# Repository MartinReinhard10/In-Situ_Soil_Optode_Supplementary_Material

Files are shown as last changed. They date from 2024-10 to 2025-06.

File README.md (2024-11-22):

This repository is to function as supplementary material for the paper "A novel, standalone and low-cost system for in-situ chemical imaging with planar optodes in soils": https://doi.org/10.1016/j.snb.2024.136894

Please find 3D files for printing structural components, wiring diagram and information on electronic + additional components required.

For Python scripts regarding operating the imaging system please refer to the repository: https://github.com/MartinReinhard10/Operate_In-Situ_Soil_Optode

# All requests or questions regarding the repository should be directed at: martinreinhard@bio.au.dk
---

# System Hardware
This is a list of electronic, mechanical, and other components used in the OptodeSystem, including a Raspberry Pi 4, HQ Camera, UV-LED, stepper motors, and various sensors. The document also includes a wiring diagram and links to additional resources for each component.

File (.step) with full 3D model of the system can be provided if needed.
---

# Electronic Components

- **Raspberry Pi 4 Model B 4 GB RAM**
    
    [Raspberry Pi Documentation - Computers](https://www.raspberrypi.com/documentation/computers/)
        
    [Armor Aluminium Heatsink Case for Raspberry Pi 4 • RaspberryPi.dk](https://raspberrypi.dk/en/product/armor-aluminium-heatsink-case-for-raspberry-pi-4/)
    
- **Raspberry Pi HQ Camera**
    
    [Raspberry Pi Documentation - Camera](https://www.raspberrypi.com/documentation/accessories/camera.html)
    
- ****16mm Telephoto Lens for Raspberry Pi HQ Camera (C-mount)****
    
    [16mm Telephoto Lens for Raspberry Pi HQ Camera (C-mount) • Mouser.com]([https://raspberrypi.dk/en/product/16mm-telephoto-lens-raspberry-pi-hq-camera/](https://www.mouser.com/pdfDocs/DFRobot16mm10MPTelephotoLensPO.pdf))
    
- **UV-LED  -** 395 nm
    
    [Datasheet UV-LED](https://www.mouser.dk/datasheet/2/245/Luminus_SST_10_UV_Datasheet-1499199.pdf)
      
- **Resistor** - HS25 18R
    
    [acl_hs10-1890310.pdf](https://www.mouser.dk/datasheet/2/303/acl_hs10-1890310.pdf)
    
- **Stepper Motor (x2) -** 17HS08-1004
    
    [Documentation - 17HS08-1004S.pdf](https://www.oyostepper.com/images/upload/File/17HS08-1004S.pdf)
    
- **Stepper Driver** - A4988
    
    [a4988_DMOS_microstepping_driver_with_translator.pdf](https://www.pololu.com/file/0J450/a4988_DMOS_microstepping_driver_with_translator.pdf)
    
    [In-Depth: Control Stepper Motor with A4988 Driver Module & Arduino](https://lastminuteengineers.com/a4988-stepper-motor-driver-arduino-tutorial/)
    
    - **A4988 Expansion Board**
        (https://store.siqma.com/stepper-motor-driver-board.html?search=expansion)
      
        [Raspberry Pi Stepper Motor Control with NEMA 17 — Maker Portal](https://makersportal.com/blog/raspberry-pi-stepper-motor-control-with-nema-17)

- **Temperature & Humidity Sensor** - DHT22
    
    [DHT22 - Datasheet.pdf](https://www.sparkfun.com/datasheets/Sensors/Temperature/DHT22.pdf)
    
- **Distance Sensor (Time-Of-Flight)** - VL53L0X
    
    [m5-docs](https://docs.m5stack.com/en/unit/tof)
    
    [Datasheet - VL53L0X_en.pdf](https://m5stack.oss-cn-shenzhen.aliyuncs.com/resource/docs/datasheet/hat/VL53L0X_en.pdf)
    
- **Limit switch (x2)**
    
    [Mechanical Endstop - RepRap](https://reprap.org/wiki/Mechanical_Endstop)
    
- **5V Relay module**
    
    [5V Single Channel Relay Module](https://microcontrollerslab.com/5v-single-channel-relay-module-pinout-working-interfacing-applications-datasheet/)
    
- **Buck Converter** - LM2596
    
    [LM2596 Buck Converter Datasheet, Pinout, Features, Applications - The Engineering Projects](https://www.theengineeringprojects.com/2020/09/lm2596-buck-converter-datasheet-pinout-features-applications.html)
    
- **12V Cooling Fan (60x60x10mm)**
  
- **Slip Ring**
    
    [SNF-3P%20updated.pdf](https://cdn.sparkfun.com/datasheets/Robotics/SNF-3P%20updated.pdf)
    
- **Power supply - 12V DC 5A**

---

# Mechanical Components

20 x 40mm V-slot Aluminum Extrusion

20mm V-Gantry Plate with Wheels
       
GT2 Belt - 2mm pitch - 6mm width

GT2 Pulley 20 (diameter: 5mm)

Belt Tensioner 2020 Profile X-Axis

Ball Bearings 8x22x7mm (x4)

---

# Other Components

Ø250mm Plexiglass Cylinder  

- Emission Filter
    
    Zircon UV Blue Blocker from Lee Filters is used to cover the camera lens.
    (https://leefilters.com/colour/821-zircon-uv-blue-blocker/)    

Wiring - See Wiring Diagram

Dupont Wire Pin Header Connectors

Cable Ties

Bolts and Nuts for Assembly - See list of nuts & bolts

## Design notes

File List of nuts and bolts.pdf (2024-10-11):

Type | M2.5 | M3 | M4 | M5 | M6
Washer | 4 | 8 | 20 | 23
Washer Large Diameter | | | | | 1
Hex Head Machine Screw 10mm 12mm 14mm 15mm 16mm 20mm 30mm 50mm 5mm 8mm | | 14 8 2 4 | 33 8 15 2 1 4 3 | 23 13 2 2 2 1 3 | 1 1
Hex Nut | 4 | 9 | 6 | 20 | 1
Internal Lockwasher | | 8 | 4 | 12
Flathead Machine screw 10mm 12mm 16mm 4mm | | 12 4 | 2 4 | 1
Philips Machine Screw 10mm 12 mm | 4 | 2
Hex Locknut | | | 1
Hex Acorn Cap Nut | | | | 2
T-Nut 2020 | | | 14

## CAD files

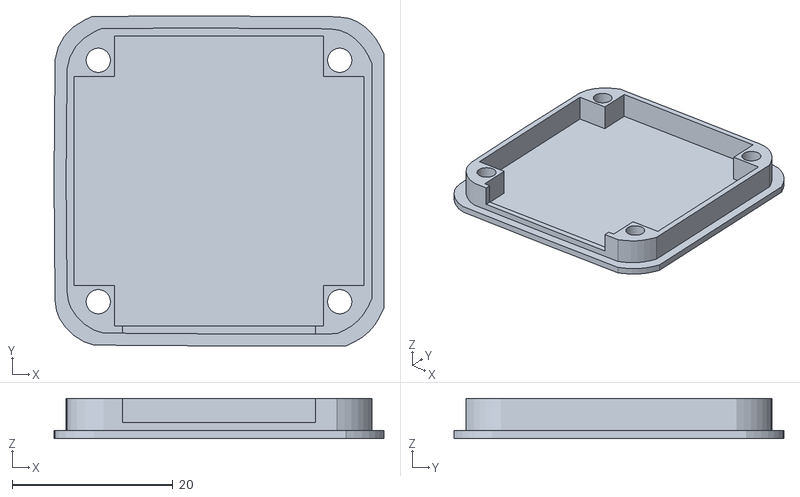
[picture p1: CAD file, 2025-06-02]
3D printing (.stl)/Pi_HQ_Cam_Back_Cover.stl
41.0 x 41.0 x 5.00

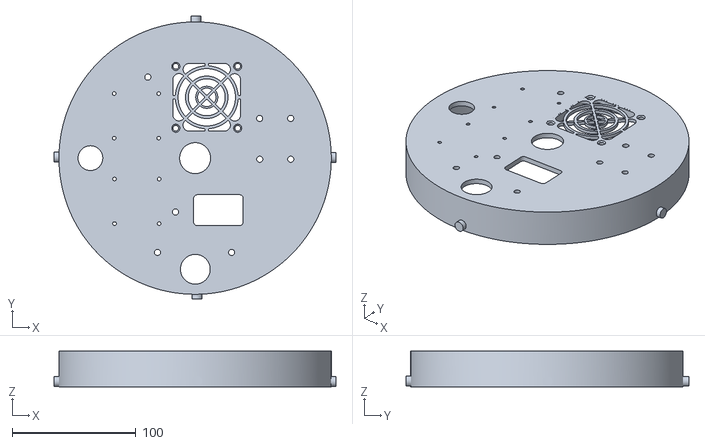
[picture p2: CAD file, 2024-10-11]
3D printing (.stl)/Baseplate.stl
227.6 x 228.6 x 29.0

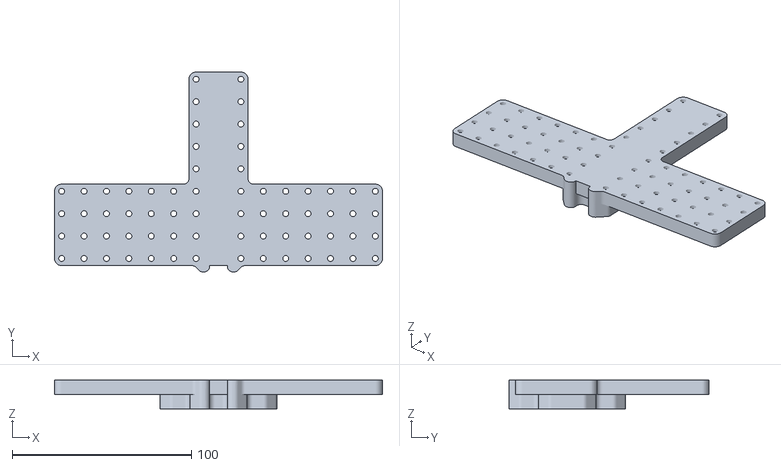
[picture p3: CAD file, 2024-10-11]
3D printing (.stl)/Backframe_mount.stl
183.0 x 111.5 x 16.0

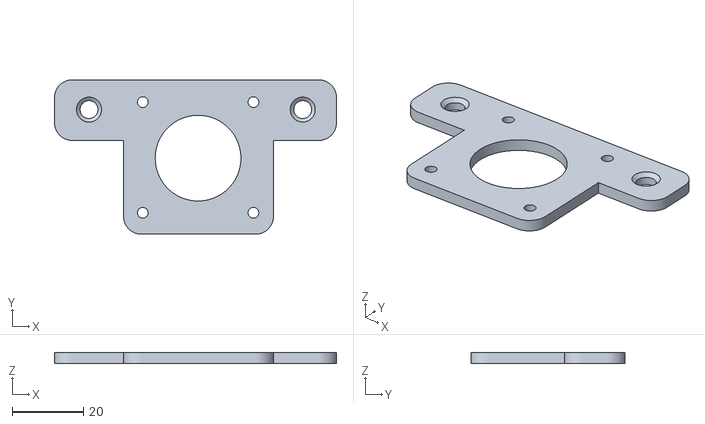
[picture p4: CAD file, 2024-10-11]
3D printing (.stl)/Motor_rotation_bracket.stl
79.0 x 43.2 x 3.00

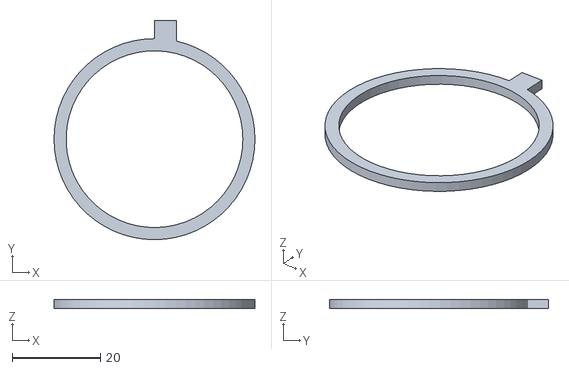
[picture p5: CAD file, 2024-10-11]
3D printing (.stl)/Filter_Lockring.stl
45.5 x 49.6 x 2.00

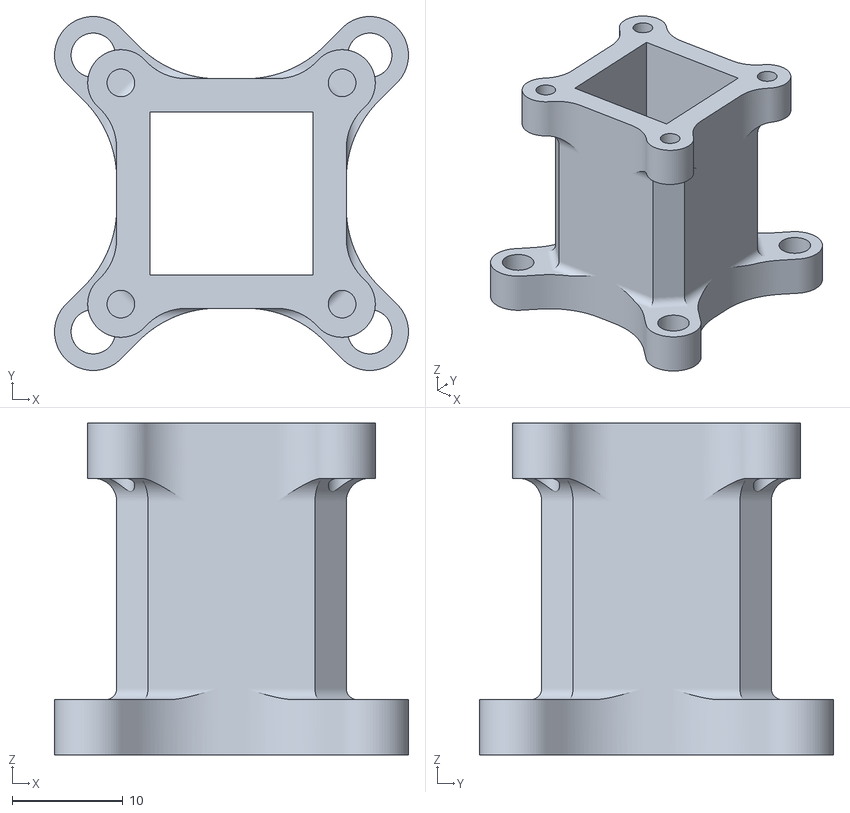
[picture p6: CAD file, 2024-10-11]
3D printing (.stl)/LED_standoff_30mm.stl
32.0 x 32.0 x 30.0

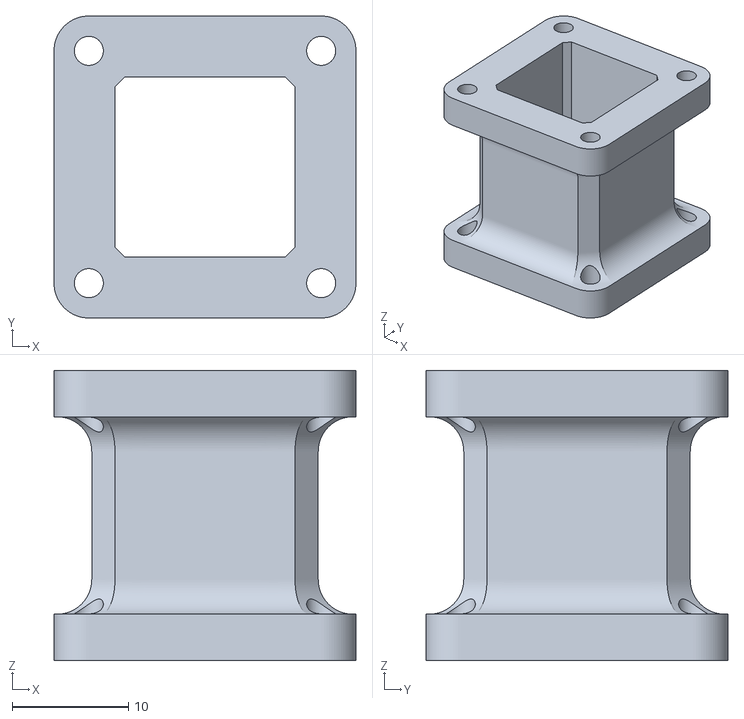
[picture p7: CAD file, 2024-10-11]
3D printing (.stl)/LED_standoff_S_25mm.stl
26.0 x 26.0 x 25.0

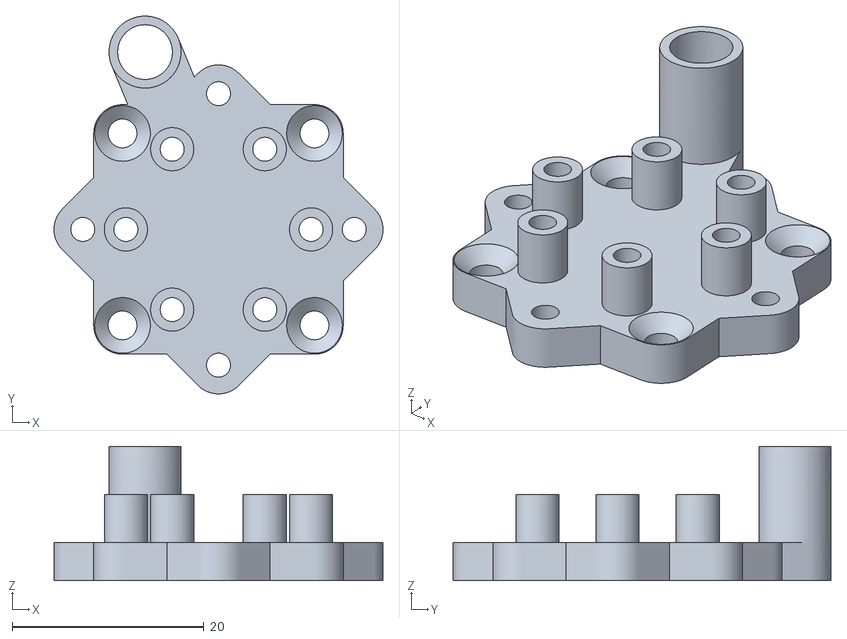
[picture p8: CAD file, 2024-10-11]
3D printing (.stl)/LED_mount.stl
34.3 x 39.4 x 14.0

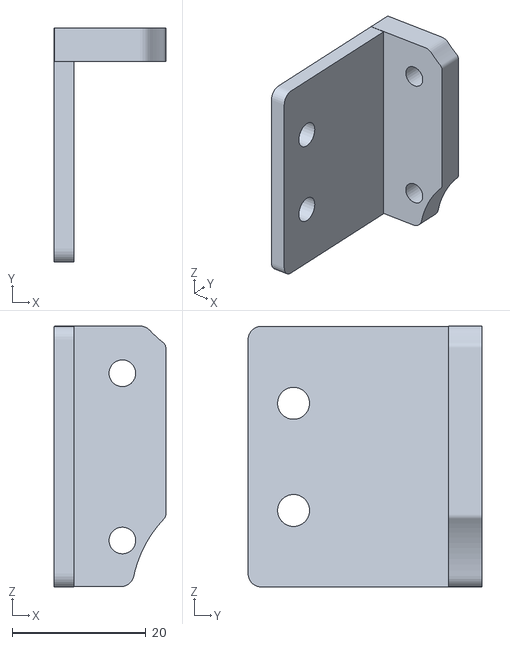
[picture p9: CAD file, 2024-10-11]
3D printing (.stl)/ToF_mount.stl
16.7 x 35.0 x 39.0

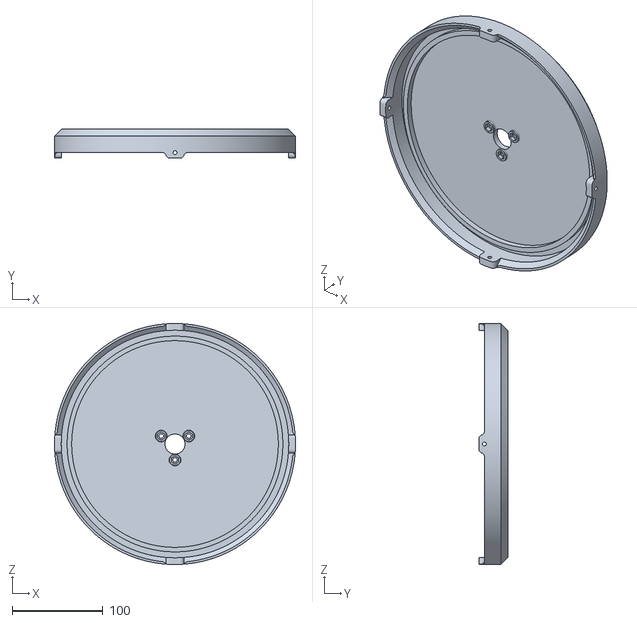
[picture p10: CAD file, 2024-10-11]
3D printing (.stl)/Lid.stl
265.0 x 32.0 x 265.0

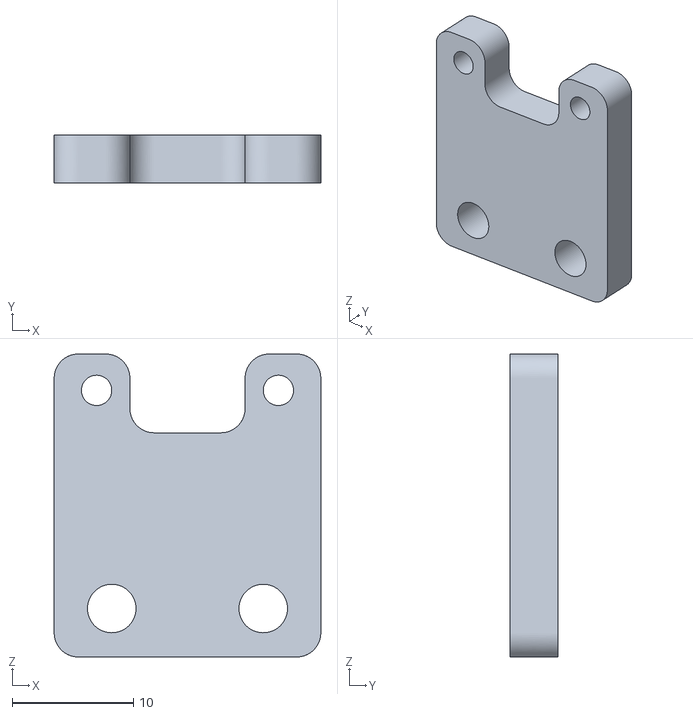
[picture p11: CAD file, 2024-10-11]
3D printing (.stl)/microswitch_mount.stl
22.0 x 4.00 x 25.0

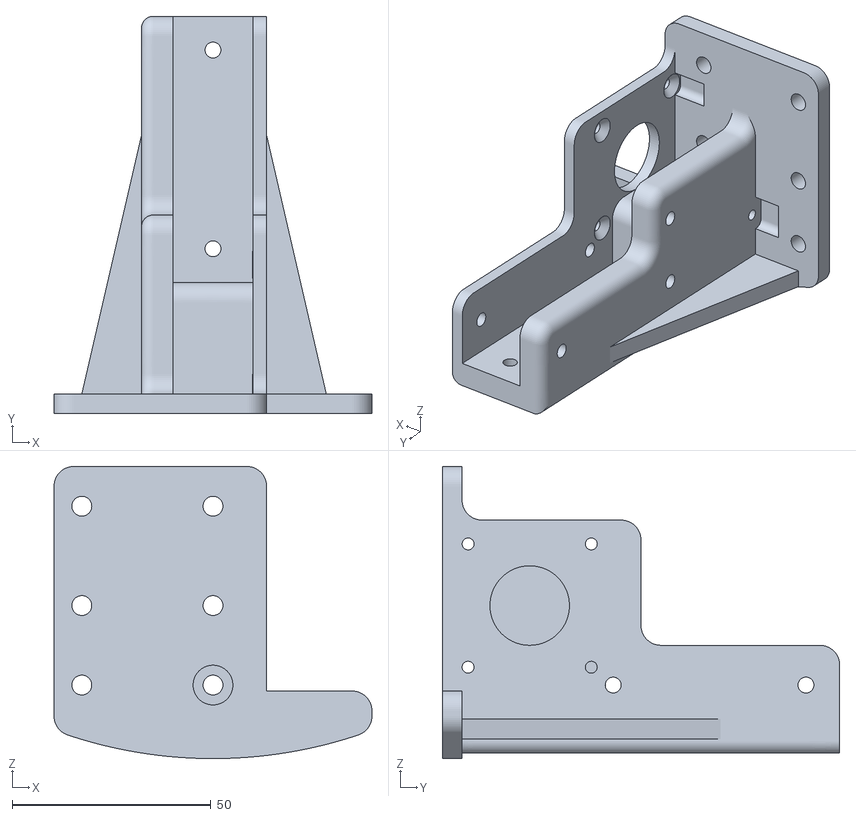
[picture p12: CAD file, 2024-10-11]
3D printing (.stl)/Rail_mount_bottom.stl
80.0 x 100.0 x 73.5

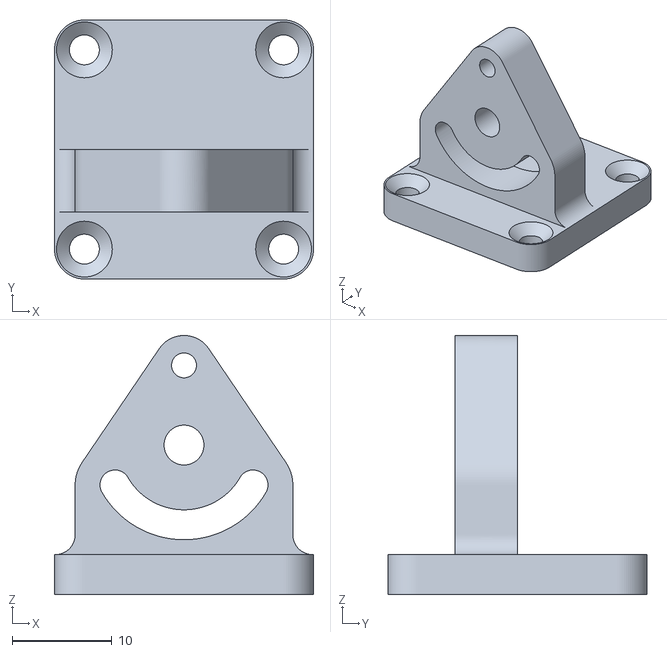
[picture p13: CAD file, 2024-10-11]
3D printing (.stl)/LED_turn.stl
26.0 x 26.0 x 26.0

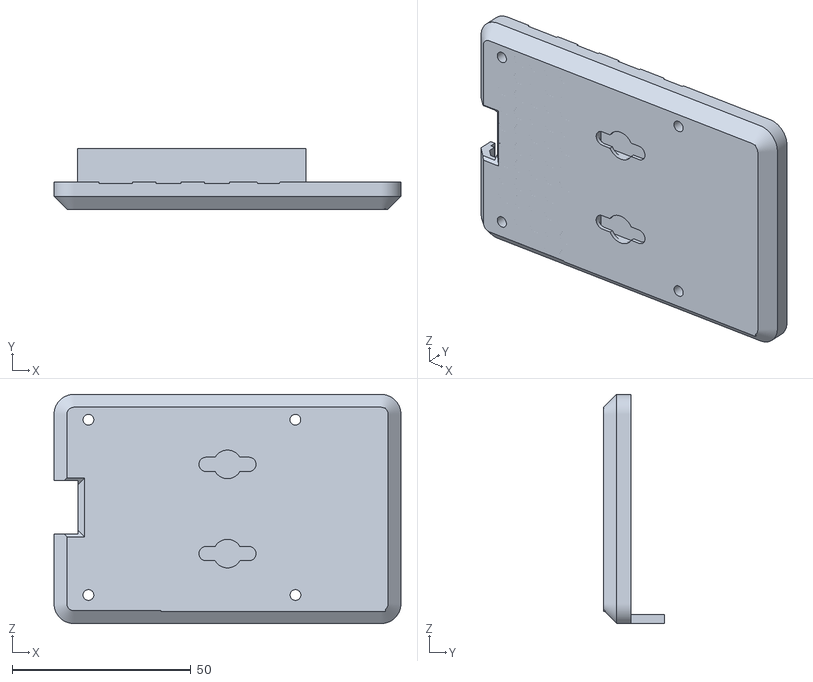
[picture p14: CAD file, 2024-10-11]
3D printing (.stl)/Pi_case_vertical.stl
97.2 x 17.0 x 64.2

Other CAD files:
3D printing (.stl)/Camera_holder.stl
3D printing (.stl)/Lens_filter_mount.stl
3D printing (.stl)/Rail_mount_top_glider.stl
3D printing (.stl)/Rotation_gear.stl
3D printing (.stl)/Gear_ring_V1.stl
3D printing (.stl)/Gear_ring_V2.stl
3D printing (.stl)/Rail_mount_top.stl

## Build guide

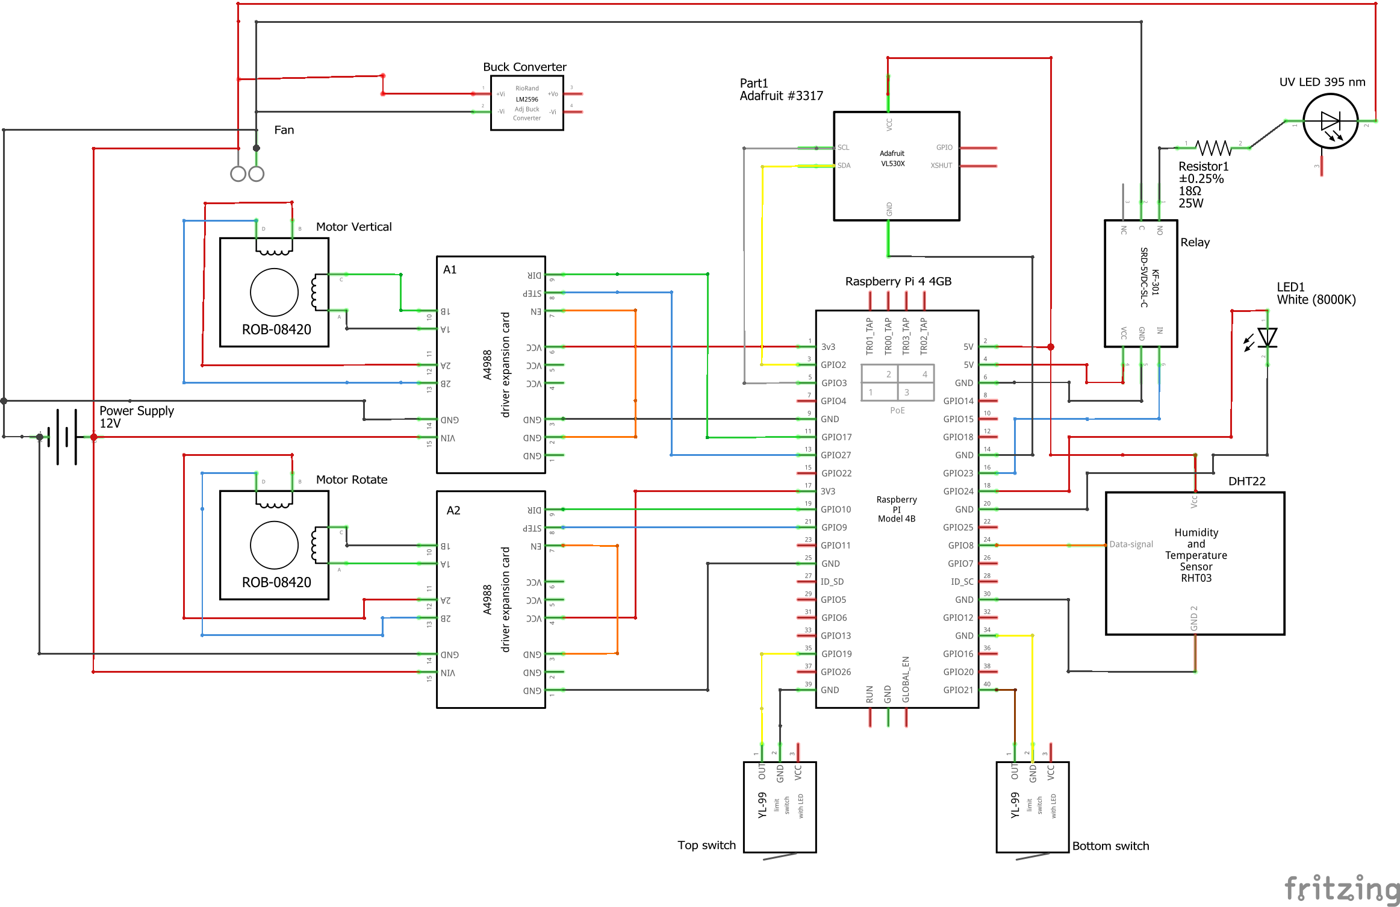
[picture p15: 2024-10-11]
Wiring_ Raspberry Pi 4.png

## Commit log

2024-10-11 .stl files for 3D printing
    [Backframe_mount.stl, Baseplate.stl, Camera_holder.stl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]
2024-10-11 List of required nuts & bolts
2024-10-11 Wiring diagram for RPi
